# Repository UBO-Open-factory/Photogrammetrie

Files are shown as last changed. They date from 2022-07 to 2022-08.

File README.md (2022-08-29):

# Photogrammetrie
This Python programme allows you to use several RaspberryPi (RPI) to take pictures of a real object.

You can use as many RPI as you want, they just have to conect them on the same wired network.

# Requirements
For this project you nead :
- As many Raspberry Pi 3+ as you want with hardware camera.
- DSLR with USB control.
- a physical structure to hold all the RPIs. So all the RPI can have a different point of view of the subject you want to scanne.
- a server (to store photos).

# Client image Disk
An image disk (.img) have been made for all your RPI. [You can found it here](./client-Install/Client_img/RPI_06.07.22_2.75Go.rar)

# Folders description

```
+---client-Install
|   +---Client
|   |   +---config
|   |   \---script
|   +---Client_img
|   +---MQTT_broker
|   \---Python-venv
+---client-programme
+---server-test
|   +---html
|   \---Script
\---structure
    +---fichiers proto
    +---files
    \---STL-for-raspberrypi
        \---images
```

## FOLDER structure
Contains the plan to build the physical structure parts.

## SUB-FOLDER : STL-for-raspberrypi
Contains all the STL files you need to build the RPI box. 

Files description can be find in file [notice de montage (FR)](./structure/STL-for-raspberrypi/notice%20de%20montage%20raspberry%20pi.pdf)

## SUB-FOLDER : files
Contains all the files you need to build the physical structure.

## FOLDER : client-install
This folder contains all the scripts needed to install:
- **Client** : The client on RPI
- **Client_img** : The last .img image disk ready to be flash with [Balena Etcher](https://www.balena.io/etcher/) or [Raspberry Pi Imager](https://www.raspberrypi.com/news/raspberry-pi-imager-imaging-utility/)

- **MQTT_brocker** : The MQTT broker on linux with mosquitto
- **python-venv** : The python virtual environment on NAS share directory

## FOLDER : client-programme
- Contains all the python programs and scripts necessary for the proper functioning of the client.

## FOLDER : server-test
- Contains the script to install a test web server on the computer containing the MQTT broker to test the proper functioning of the client.

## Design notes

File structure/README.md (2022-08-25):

This directory contains the plans to build the physical structure parts.

# STL-for-raspberrypi
Contains all the STL files you need to build the RPI box. 

Files description can be find in [notice de montage (FR)](./structure/STL-for-raspberrypi/notice%20de%20montage%20raspberry%20pi.pdf)

# files
Contains all the files you need to build the physical structure.

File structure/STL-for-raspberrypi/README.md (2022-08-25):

# Notice de montage du boîtier Raspberry pi
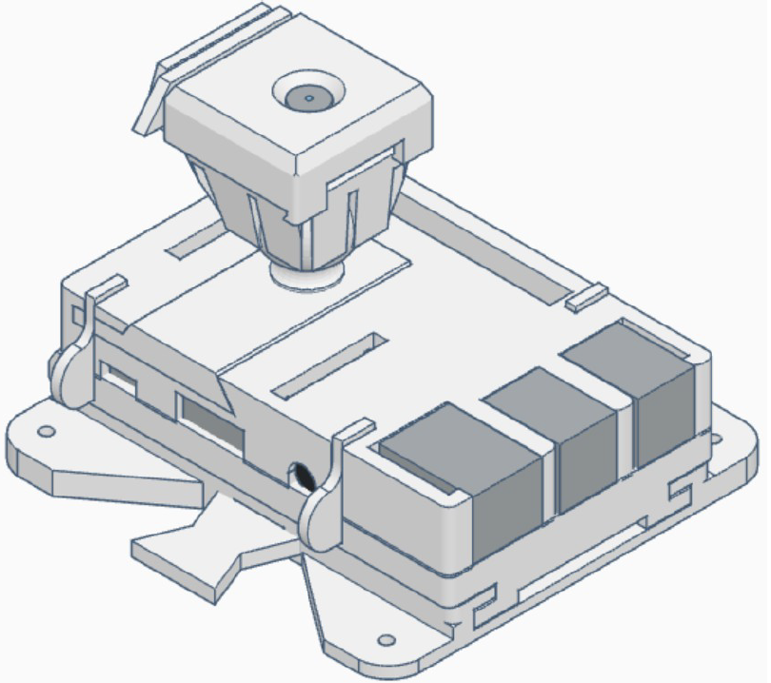
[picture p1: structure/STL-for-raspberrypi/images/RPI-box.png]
RPI Box


# Description
## Présentation
Le boîtier de photogrammétrie Raspberry pi est une coque de protection sur laquelle à été rajoutée
un support d’appareil photo Raspberry sous forme d’une rotule. De nombreuses fonctionnalités ont
été mises en place afin de permettre une utilisation et un entretien simplifié.
L’intégralité des pièces sont imprimables en 3D, les dimensions du modèle lorsque la caméra est
droite sont de 9,4 cm de long pour 9 cm de large pour 6,6 cm de hauteur. Afin de fixer la base du
boîtier à son support, quatre vis ou alternatives doivent être utilisés. Les trous sont adaptés à des vis
M3 (les plus courantes).
Pour n’importe quelle question ou interrogation, n’hésitez pas à contacter à l’adresse mail (celle
adaptée à la photogrammétrie à l’UOF)

## Fonctionnalités
Le boîtier possède plusieurs fonctionnalités adaptés à une utilisation optimale pour la
photogrammétrie.
- Le boîtier du Raspberry pi peut être retiré de son support (qui lui est fixé à la structure par 4 vis)
lorsqu’une goupille est enlevée, et que le technicien fait glisser la partie supérieure du boîtier le
long de la glissière mise en place.
- Deux goupilles sont proposés, une première adaptée pour des changements fréquents (moins
sécuritaire) déplaçable à la main, sans éléments bloquants autres que par la friction entre les pièces
et la gravité (expliqué dans la partie Utilisation), une seconde qui est adaptée pour une sécurité
optimale, utilisant une vis du support comme élément bloquant afin d’éviter que la goupille ne parte
via des secousses ou des personnes mal avisées.
- Le support du boîtier possède une butée permettant d’installer précisément la partie supérieure
pour une problématique de résistance mécanique optimale, Mais il est important de savoir que les
modèles sont adaptés afin que la partie supérieure puisse être installée dans les deux sens, afin
d’éviter des tensions et des longueurs problématique des câbles de ralliement aux Switch ou aux
serveurs.
- Le boîtier est muni d’un support pour l’appareil photo Arduino dans sa version 2.1, qui peut être
tourné et fixé sans forces extérieures appliquées dans trois degrés de liberté.
- des emplacements en dessous de la partie supérieure de la glissière ont été faits afin de noter au
marqueur ou via un post-it les noms des supports et des Raspberry associés, lorsque plusieurs
boîtiers doivent être enlevés, ou que plusieurs structures sont exploitables avec un nombre limité de
Raspberry.
- Le boîtier possède une ouverture large et adaptée à tout type de doigts situé à l’arrière du boîtier
pour permettre l’accessibilité à la carte microSD du Raspberry sans avoir à démonter des pièces.
- Le boîtier est entièrement montable et démontable sans outils.
- L’intégralité des ports du Raspberry pi sont disponibles si une utilisation alternative du boîtier
devait être mise en place.
- L’intégralité des pièces sont fixés mécaniquement entre elles via des goupilles utilisant la
déformation élastique de goupilles afin de tenir. Les matériaux utilisés pour la confection de ces
goupilles doivent donc être choisis pertinemment pour un bon compromis entre sécurité et
utilisabilité.
- Les pièces (en particulier les goupilles) ont été étudiés pour casser sans invalider les pièces
auxquelles elles sont rattachées. Si le boîtier venait à tomber, les bouts des pièces cassées pourront
être enlevés, et la pièce ré-imprimée remplacera l’ancienne sans problèmes (sauf déformation
plastique sans rupture des pièces)

## Notions d’utilisation
- Le support des pièces doit être mis en place de préférence dans une position ou la butée du support
est orientée vers le bas. Même chose pour la goupille sans blocage (une seule position de la goupille
avec blocage par vis est admissible sur le système) qui doit être positionnée de manière à voir sa
tête orientée vers le haut, ou dans une position encourageant la gravité à bloquer la tête contre le
support.
- La position du support de l’appareil photo permet une liberté intéressante des angles que peut
prendre la caméra, néanmoins la solution technologique utilisée afin de la garder en place possède
des limites parfois floues. Premièrement, la position du support ne doit pas mettre en tension les
câbles du système sous peine d’un dysfonctionnement ou de l’endommagement du câble rendant le
système inutilisable. De plus, La rotule et son support peuvent facilement se disloquer lorsque
l’angle pris du support de la caméra est trop grand. Afin d’éviter ce problème, vérifiez lorsque
l’angle est fort que la tête de la boule est bien au fond de la cavité du support via les rainures. De
toute manière, évitez les angles supérieurs à 45 degrés sur le système.
- La glissière support est une pièce qui s’est révélée nécessaire lors de la confection du système
dans un soucis de facilité d’impression. Elle peut également être enlevée lorsque l’utilisation du
boîtier ne demande pas d’appareil photo, ou peut être modifié afin de permettre une utilisation
alternative.

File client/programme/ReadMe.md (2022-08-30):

# PROGRAMMES
| Name | Function |
|--- | --- |
|connect.sh | Script start at the boot of RPI |
|boot.py | send mac_address to **Register** topic |
|Prog.py | RPI client |
|mac.sh | write mac_address on '/home/pi/mac' file |
|errorGPIO.py | make red led flashes |

# SCHEMA
## General
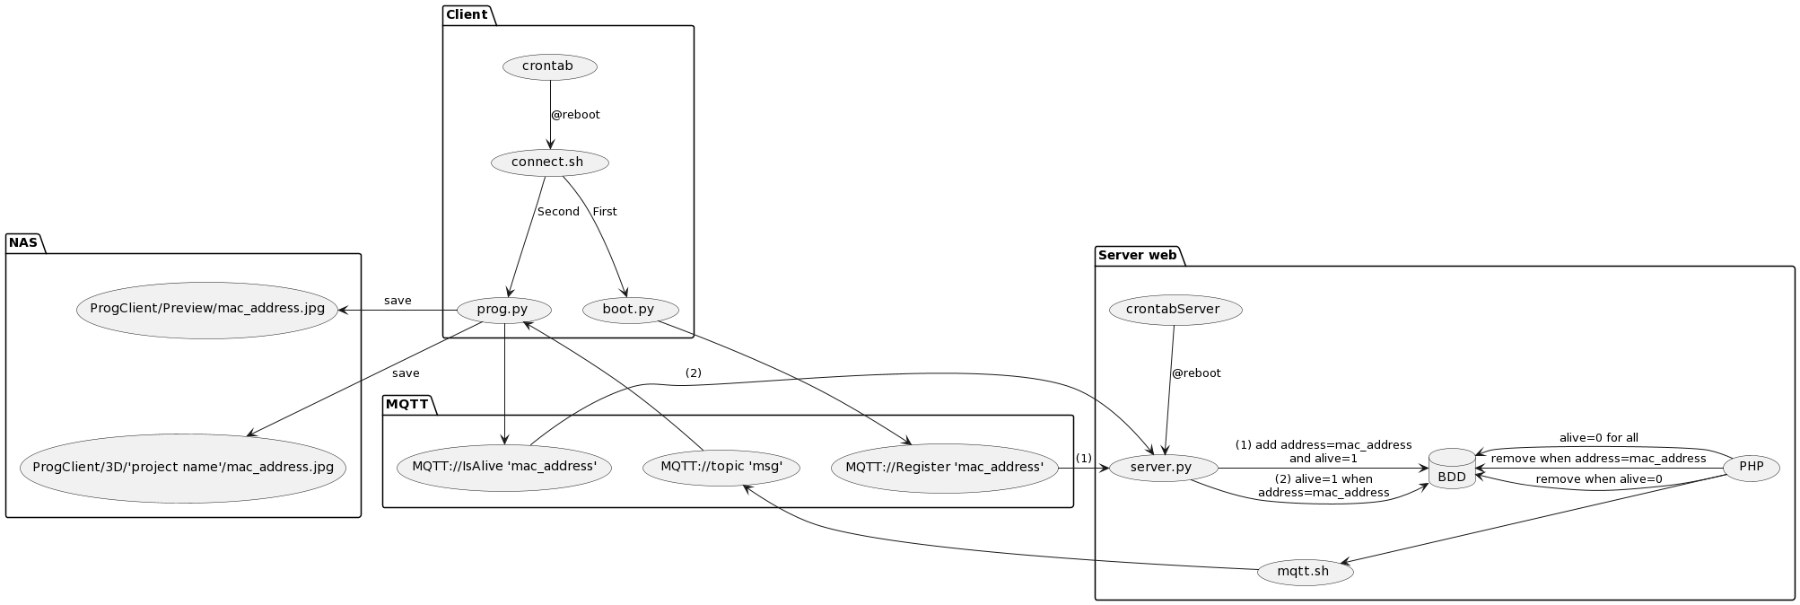
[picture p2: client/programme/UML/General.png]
General

## Mqtt
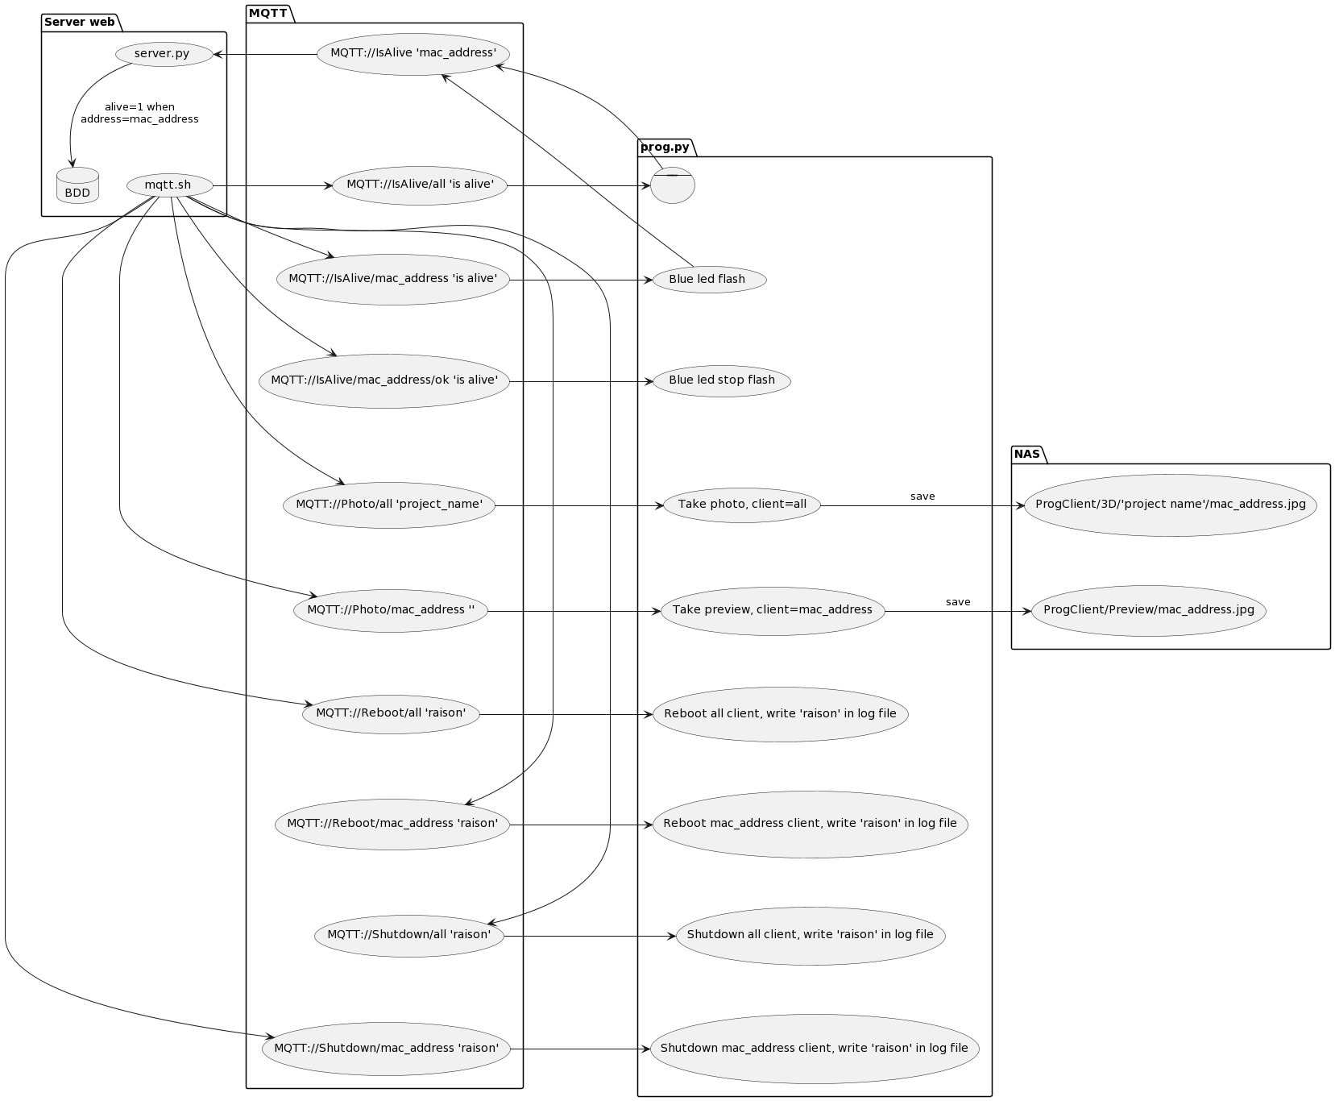
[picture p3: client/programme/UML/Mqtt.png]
MQTT


# MESSAGE MQTT

| Topic | Message | Action | Exemple 									  					 |
| --- | --- | --- | ---|
| Photo/all | **Directory_name** | take picture and store them in directory send in message with name  **mac_address.jpg** |-topic: Photo/all -message: 'Project_directory' |
| Photo/**mac_address** | **what_you_want**  | take picture and store them in **Preview** directory with name **mac_address.jpg** |-topic: Photo/34-fr-34-fr-34 -message: '' |
| Reboot/all | **why** | Reboot all RPI and write why in log file |-topic: Reboot/all -message: 'reboot_for_maintenance' |
| Reboot/**mac_address** | **why** | Reboot RPI with the name mac_address name and write why in log file |-topic: Reboot/34-fr-34-fr-34 -message: 'reboot_for_refresh' |
| Shutdown/all | **why** | Shutdown all RPI and write why in log file |-topic: Shutdown/all -message: 'shutdown_for_maintenance' |
| Shutdown/**mac_address** | **why** | Shutdown RPI with the name mac_address name and write why in log file |-topic: Shutdown/34-fr-34-fr-34 -message: 'shutdown_for_replacement' |
| IsAlive/all | is alive | All RPI reply by sending their name to **IsAlive** topic |-topic: IsAlive/all -message: 'is alive' |
| IsAlive/**mac_address** | is alive | RPI with the name mac_address reply by sending their name to **IsAlive** topic and make blue led flash |-topic: IsAlive/34-fr-34-fr-34 -message: 'is alive' |
| IsAlive/**mac_address**/ok | is alive | Stop blue led flash |-topic: IsAlive/34-fr-34-fr-34/ok -message: 'is alive' |

All **bold** part may be changed for write the good mac address and the good message

# LUMINOUS MEANING

| Red led | Green led | State |
| --- | --- | --- |
| Off | Off | RPI off or no link with the switch |
| On | Off | Error when mount share directory |
| Flashes | Off | Error whith connection to the MQTT broker |
| Flashes | On | The RPI is connect and disconnect multiple times maybe two RPI have the same name |
| On | On | The python programm have crashed |
| Off | On | The python programm working |
| Off | Flashes | For locate RPI when you send a specific message |

# BRANCHEMENTS

| Name | Pin  |
|--- | ---- |
| GND | 14 |
| LED_BLUE | 12 |
| LED_RED  | 16 |

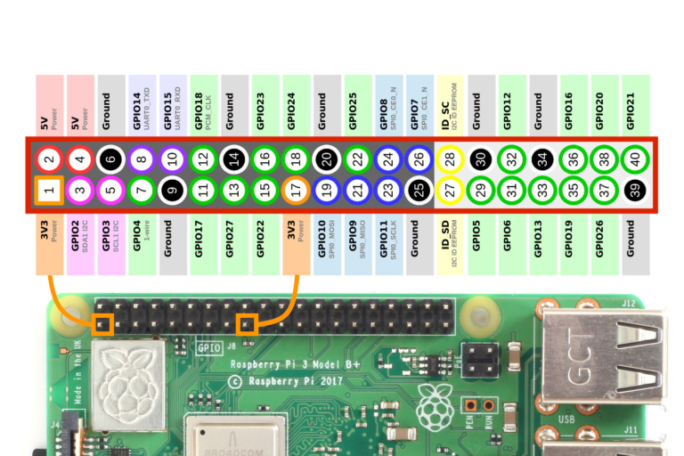
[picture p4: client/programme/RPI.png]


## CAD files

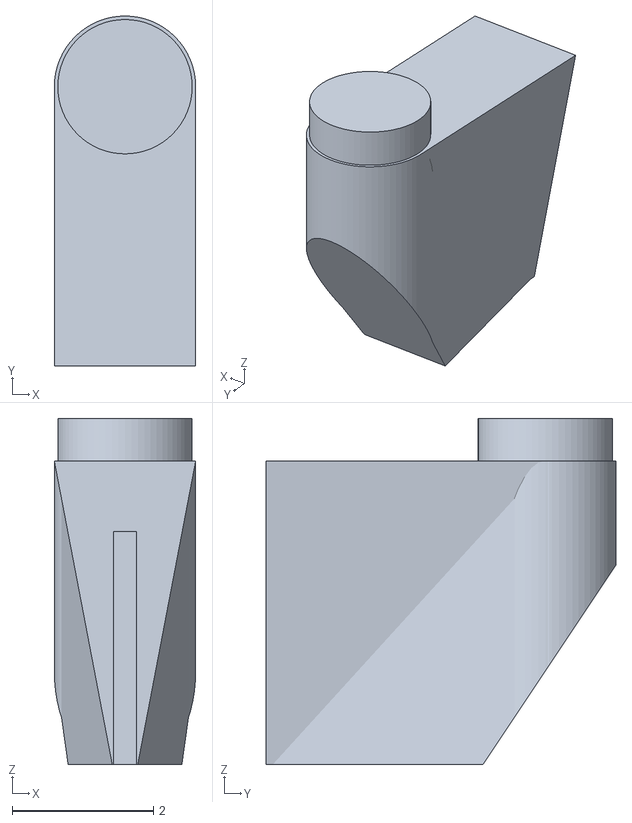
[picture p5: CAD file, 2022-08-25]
structure/fichiers proto/coin pied.stl
2.00 x 4.95 x 4.90

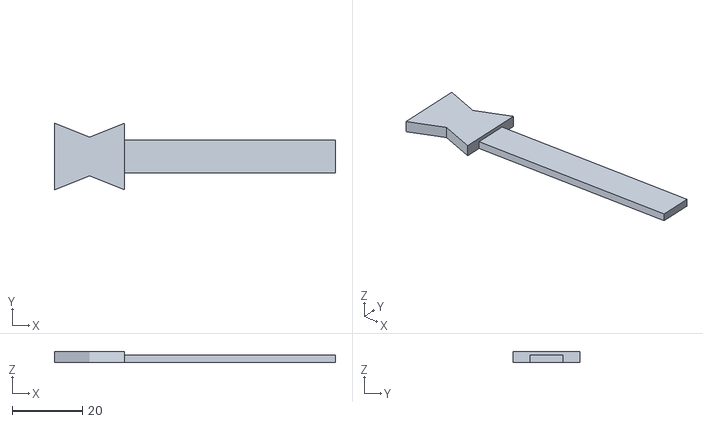
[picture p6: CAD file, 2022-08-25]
structure/STL-for-raspberrypi/11.stl
80.0 x 19.0 x 3.00

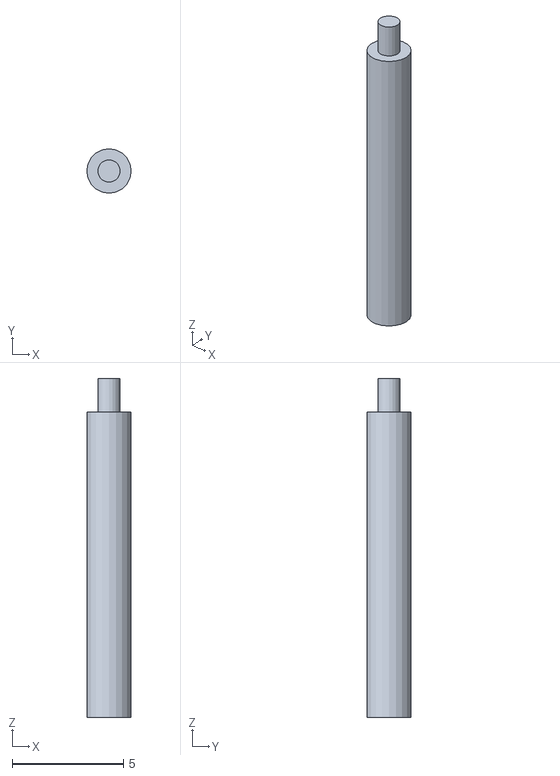
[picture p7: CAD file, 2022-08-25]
structure/fichiers proto/tige.stl
2.00 x 2.00 x 15.3

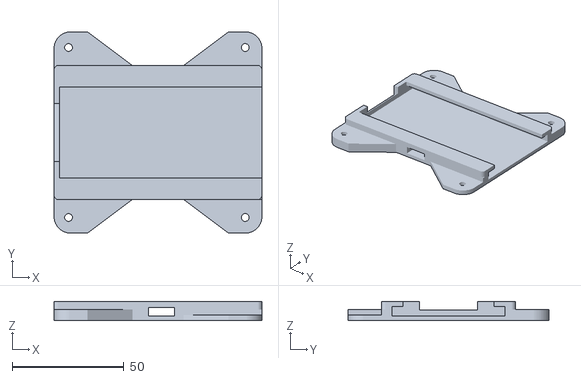
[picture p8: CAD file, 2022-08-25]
structure/STL-for-raspberrypi/10.stl
93.0 x 90.0 x 8.50

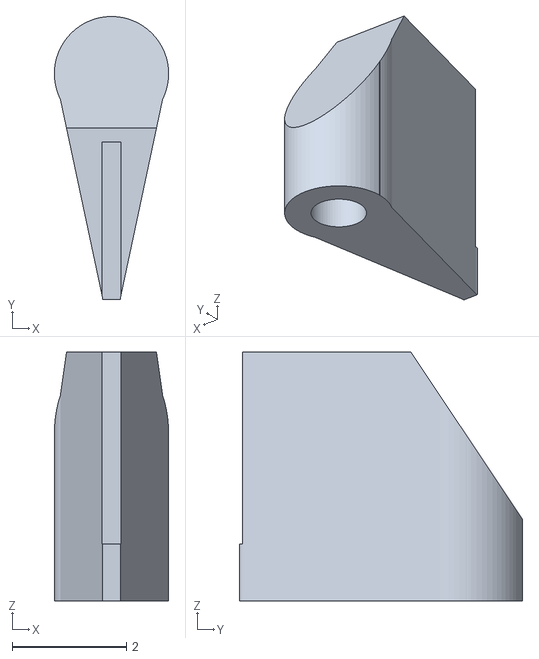
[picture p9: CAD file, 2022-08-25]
structure/fichiers proto/coin femelle.stl
2.00 x 4.95 x 4.35

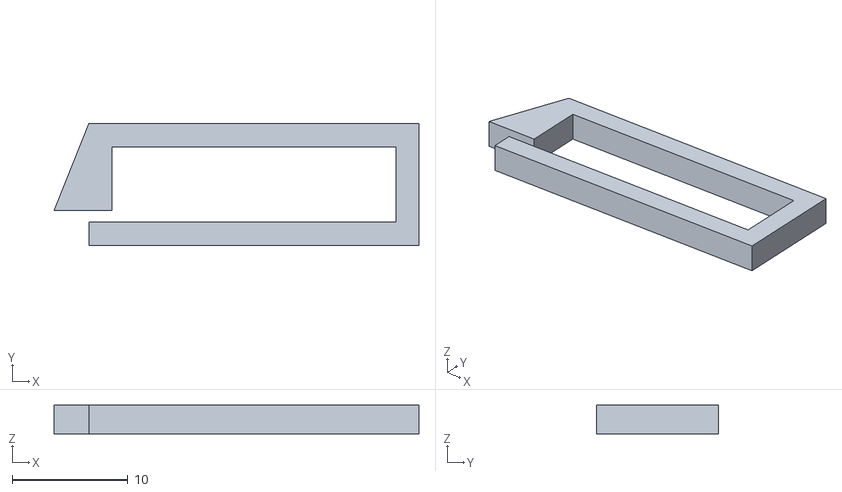
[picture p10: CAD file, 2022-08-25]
structure/STL-for-raspberrypi/9.stl
31.5 x 10.5 x 2.50

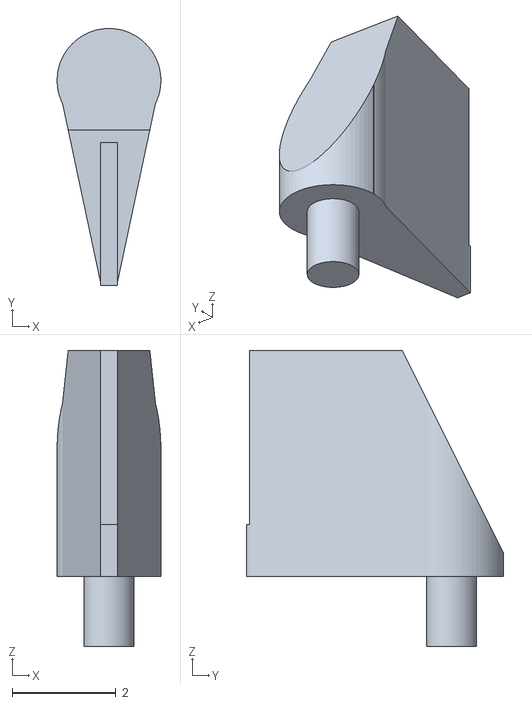
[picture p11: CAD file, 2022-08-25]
structure/fichiers proto/coin male.stl
2.00 x 4.95 x 5.70

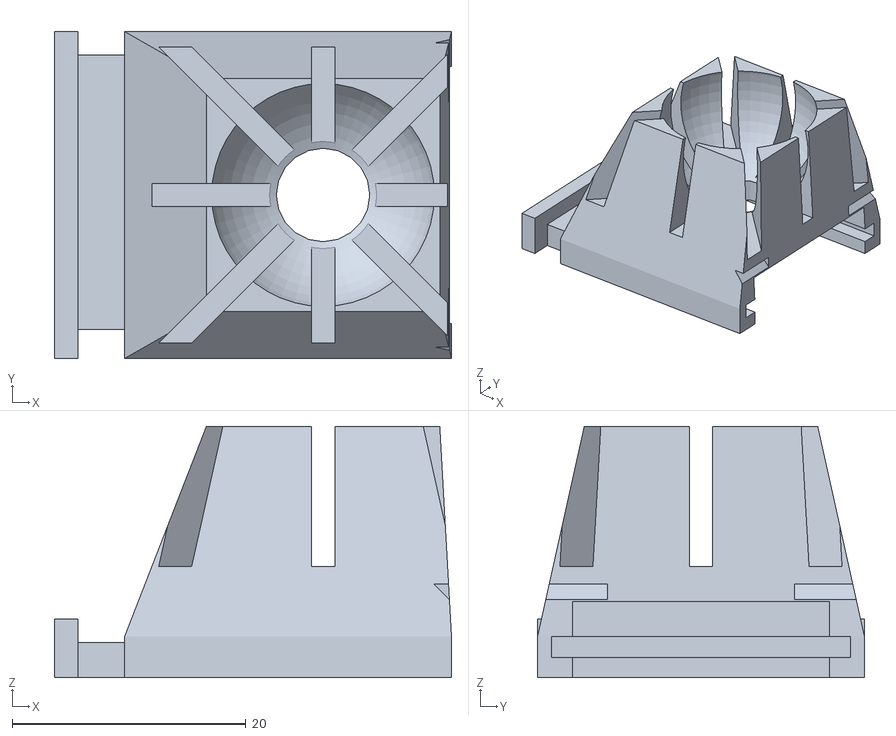
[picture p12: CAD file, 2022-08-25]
structure/STL-for-raspberrypi/6.stl
34.0 x 28.0 x 21.5

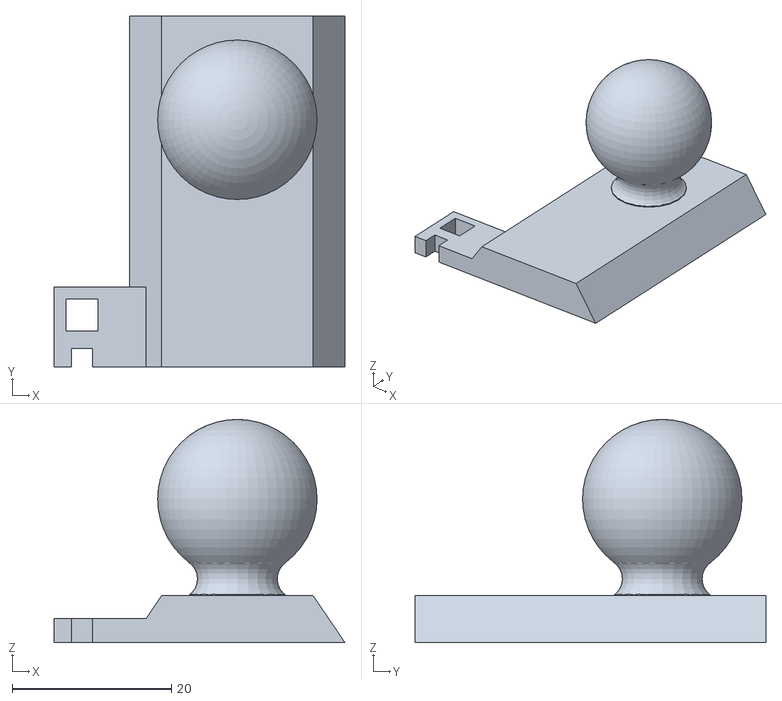
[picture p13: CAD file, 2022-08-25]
structure/STL-for-raspberrypi/4.stl
36.5 x 44.0 x 28.0

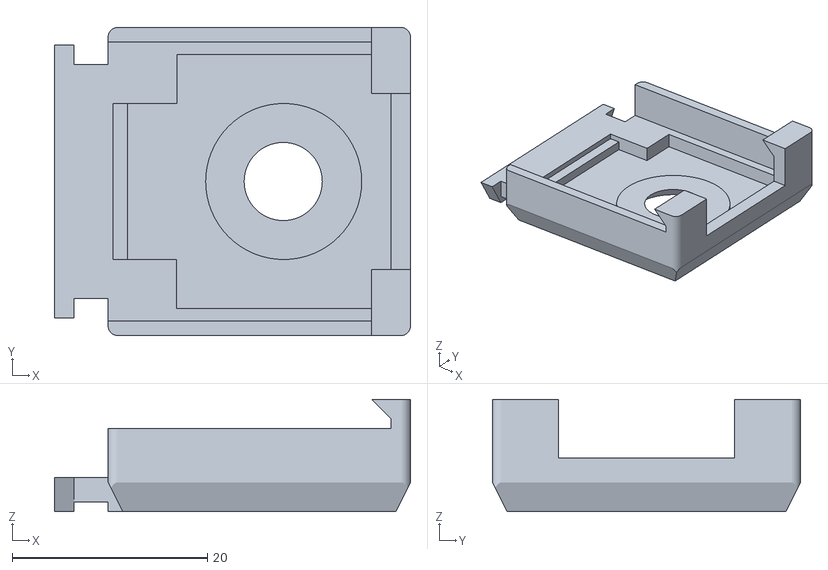
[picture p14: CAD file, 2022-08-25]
structure/STL-for-raspberrypi/8.stl
36.5 x 31.6 x 11.5

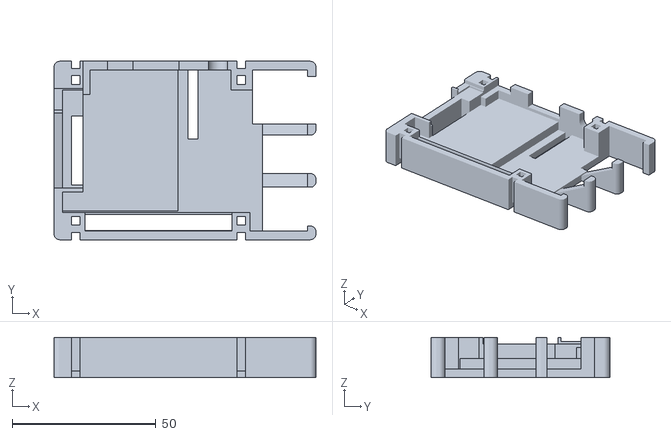
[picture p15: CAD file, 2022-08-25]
structure/STL-for-raspberrypi/2.stl
91.0 x 62.0 x 14.0

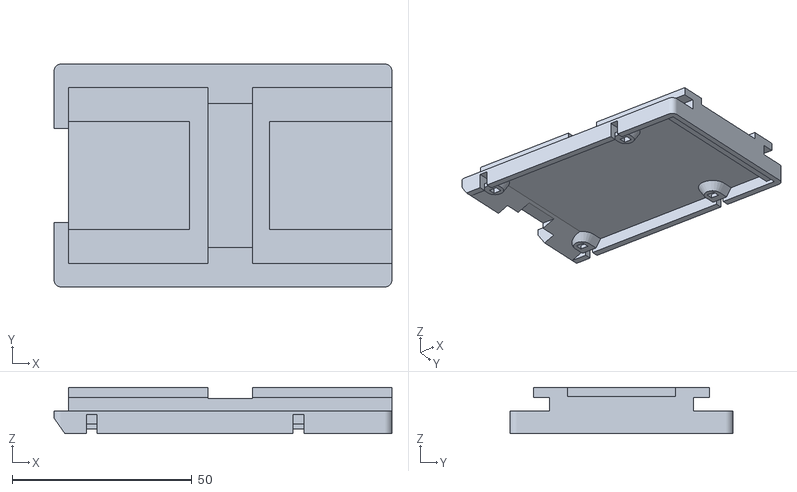
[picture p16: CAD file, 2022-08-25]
structure/STL-for-raspberrypi/3.stl
94.0 x 62.0 x 12.8

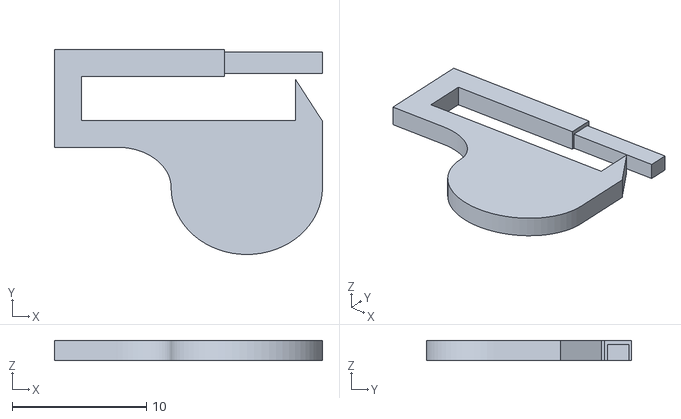
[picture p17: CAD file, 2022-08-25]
structure/STL-for-raspberrypi/5.stl
20.0 x 15.3 x 1.50

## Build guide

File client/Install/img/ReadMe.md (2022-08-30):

# Creation of an .img file
1. Installation of client on blank RPI via install's script
2. Partition resizing with Gparted to 2.75Go
3. Create img with Win32DiskImager from the [Raspberry Pi Downloads Page](https://www.raspberrypi.com/software/) or from [sourceforge](http://sourceforge.net/projects/win32diskimager/files/latest/download)
4. Zip file with WinRar

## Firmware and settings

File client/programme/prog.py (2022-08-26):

#!/usr/bin/env python3
# -*- coding: utf-8 -*-

#----------------------------------------------------------------------------
# Created By  : Titouan Melon
# Created Date: 10/07/22
# version ='3.0'
# ---------------------------------------------------------------------------

""" Create a client that connects to an MQTT broker and wait for message.
    When he receive a message it performs an action associated with the message"""

# Import libraries ----------------------------------------------------------
import paho.mqtt.client as mqtt
import RPi.GPIO as GPIO
import time
import datetime
import os
import sys
# ---------------------------------------------------------------------------

#global variable-------------------------------------------------------------
global mac_address
nb_reconnect = 0
# ---------------------------------------------------------------------------

# const variable ------------------------------------------------------------
BROKER_IP = sys.argv[1]
DSLR=int(sys.argv[2])
# ---------------------------------------------------------------------------

#Callback function ----------------------------------------------------------
def on_log(client, userdata, level, buff):
	""" Write log in the log file when a log interrupt is raise by the client"""
	error = buff
	f = 0
	if ((error == "Sending PINGREQ") or (error == "Received PINGRESP")):
		f = open("/home/pi/watchdogLog/log", "a")
	else:
		f = open("/var/log/MQTT/log", "a")
	f.write(datetime.datetime.now().strftime('[%d.%m.%y_%H.%M.%S]')+error+'\n')
	f.close()

def on_connect(client, userdata, flags, rc):
	""" When we are connected to the broker we suscribe
	to topic use by the programm and count the number
	of time this function is called to detect multiple
	connection"""
	global nb_reconnect
	global led_error
	print ("connected with result code" + str(rc))
	nb_reconnect+=1
	if (nb_reconnect == 4): #client connect/disconnect more than four times so make Error signal (led red 0.5s on / 0.5s off)
		os.system("python errorGpio.py 2 50 &")
	elif (nb_reconnect < 4):
		GPIO.output(23, False) #else turn off red led

	# Suscribe to a project
	ourClient.subscribe("Photo/"+mac_address[0]+"/#")
	ourClient.subscribe("Photo/all")

	ourClient.subscribe("Reboot/all")
	ourClient.subscribe("Reboot/"+mac_address[0])

	ourClient.subscribe("Shutdown/all")
	ourClient.subscribe("Shutdown/"+mac_address[0])

	ourClient.subscribe("IsAlive/all")
	ourClient.subscribe("IsAlive/"+mac_address[0]+"/#")

    #Write we are connected to the broker in log file
	f = open("/var/log/MQTT/log", "a")
	f.write(datetime.datetime.now().strftime('[%d.%m.%y_%H.%M.%S]')+"Connexion réussie\n")
	f.close()
	GPIO.output(18, True) #turn on blue light

def messageFunction (client, userdata, message):
	""" When client receive a message on one of this suscribe topic
	this function was called and analyse the message to execute
	the correct action"""
	global blue_flip_flop
	topic = str(message.topic).split('/') #We divide the topic by '/' character
	message = str(message.payload.decode("utf-8"))

	if (topic[0] == "Reboot"): #Reboot pi
		if (len(topic) > 1):
			if (topic[1] == mac_address[0]) or (topic[1] == "all"): #If it is just me or all
				f = open("/var/log/MQTT/log", "a")
				f.write(datetime.datetime.now().strftime('[%d.%m.%y_%H.%M.%S]')+"Reboot : "+message)
				f.close()
				os.system("sudo reboot")
				os.system("killall -9 python3")

	if (topic[0] == "Shutdown"): #Reboot pi
		if (len(topic) > 1):
			if (topic[1] == mac_address[0]) or (topic[1] == "all"): #If it is just me or all
				f = open("/var/log/MQTT/log", "a")
				f.write(datetime.datetime.now().strftime('[%d.%m.%y_%H.%M.%S]')+"Shutdown : "+message)
				f.close()
				os.system("sudo shutdown -h now")
				os.system("killall -9 python3")

	if (topic[0] == "Photo"): #Take photo
		if (len(topic) > 1):
			if (topic[1] == "all"): #Take photo and save it on NAS with the name : Date+message
				os.system("sudo mkdir ../../3D/"+message)
				str_cmd = "sudo raspistill -t 1 -q 100 -o ../../3D/"+message+"/"+mac_address[0]+".jpg"
				os.system(str_cmd)
				if (DSLR == 1): #Take photo with the DSLR if have one
					os.system("gphoto2 --capture-image-and-download")
					os.system("mv ./*.jpg ../../3D/"+message+"/DSLR_"+mac_address[0]+".jpg")
			if (topic[1] == mac_address[0]): #Take photo and save it on NAS with the name : mac_address + preview
				str_cmd = "sudo raspistill -t 1 -q 25 -w 100 -h 100 -o ../../Preview/"+mac_address[0]+".jpg"
				os.system(str_cmd)
				if (DSLR == 1): #Take photo with the DSLR if have one
					os.system("gphoto2 --capture-image-and-download")
					os.system("mv ./*.jpg ../../Preview/DSLR_"+mac_address[0]+".jpg")

	if (topic[0] == "IsAlive" and message == "is alive"): #Server want know if i'm alive or not
		if (len(topic) > 1):
			if (topic[1] == mac_address[0]):
				if (len(topic) > 2):
					if (topic[2] == "ok"):
						blue_flip_flop.start(100)
				else:
					blue_flip_flop.start(50)
					print ("Demande de vie demande")
					client.publish("IsAlive", mac_address[0])
			if (topic[1] == "all"):
				print ("Demande de vie demande")
				client.publish("IsAlive", mac_address[0])

# ---------------------------------------------------------------------------

# main ----------------------------------------------------------------------

#Write the mac address in the /home/pi/mac file ----
os.system('sudo ./mac.sh')
filin = open("/home/pi/mac", "r")
mac_address = filin.readlines()
for i in range(len(mac_address)): #replace the ':' by '-'
	mac_address[i] = mac_address[i].replace(':', '-')
	mac_address[i] = mac_address[i][:-1] #remove the '\n'
filin.close()
#---------------------------------------------------

GPIO.setmode(GPIO.BCM)
GPIO.setup(18, GPIO.OUT) #blue led
GPIO.setup(23, GPIO.OUT) #red led

blue_flip_flop = GPIO.PWM(18, 1) #Make PWM blue led variable

ourClient = mqtt.Client(mac_address[0]) #Create client with mac address for the name
ourClient.on_log = on_log #define the callback function for log
ourClient.on_connect = on_connect #Define the connect callback for when we are connected
ourClient.on_message = messageFunction #Define the callback function for when the client receive a message

# Login et mot de passe
#ourClient.username_pw_set(username="montotof",password="trucmuche")

# Connexion to MQTT broker
try:
	ourClient.connect(BROKER_IP, 1883)
except:
	f = open("/var/log/MQTT/log", "a")
	f.write(datetime.datetime.now().strftime('[%d.%m.%y_%H.%M.%S]')+"Erreur lors de la connexion au serveur\n")
	f.close()
	os.system("python errorGpio.py 1 50 &")

# Start client loop
ourClient.loop_forever()
# ---------------------------------------------------------------------------

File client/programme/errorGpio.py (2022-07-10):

#!/usr/bin/env python3
# -*- coding: utf-8 -*-

#----------------------------------------------------------------------------
# Created By  : Titouan Melon
# Created Date: 10/07/22
# version ='3.0'
# ---------------------------------------------------------------------------

""" Make led on pin 23 of GPIO flash with frequency and duty cycle
    give in parameters"""

# Import libraries ----------------------------------------------------------
import RPi.GPIO as GPIO
import sys
# ---------------------------------------------------------------------------

# main ----------------------------------------------------------------------
#Setup PWM for pin 23
GPIO.setmode(GPIO.BCM) #Type of access to the GPIO
GPIO.setup(23, GPIO.OUT) #Set pin 23 in output mode
p= GPIO.PWM(23, int(sys.argv[1])) #Set the frequency of the PWM
p.start(int(sys.argv[2])) #Start the PWM and set the duty cycle

while(1): #make the programm loop forever
	a=0

# ---------------------------------------------------------------------------
